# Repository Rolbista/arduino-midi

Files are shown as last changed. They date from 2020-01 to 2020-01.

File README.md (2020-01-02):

# MidiBoi™

MidiBoi™ is a controller designed for use with Korg® Monologue™. It is literally just two reprogrammable mod wheels.  
Because Monologue™ only has one pitch-stick, dynamic modulation is limited when playing by hand since it's  impossible  
to do, for example, pitch bend and add vibrato at the same time conveniently. LFO int knob is on the other side of  
the synthesizer. Why not use a standard MIDI keyboard with normal wheels then? Well, while standard Pitch Bend MIDI  
message is accepted and interpreted by the synth, Mod Wheel message is not. LFO intensity is assigned to MIDI CC 26  
so it won't react unless you reprogram the wheel to send it. I could not find a controller that would let me do this,  
space was also a consideration - since the Monologue™ already has a keyboard and doesn't exist in a module form apart  
from some risky looking mods, why take up space with another if two wheels are all that is necessary to add  
expressiveness to the interface? Potentiometers with programmable CC messages are useful in cases where hardware is  
fixed and cannot easily accept a different value like you would on a DAW by just using MIDI Learn. While it was built  
with a specific model in mind, this can be used with other synthesizers as well if you need additional mod wheel or  
two or want a comfortable wheel to steer a parameter not present on the panel.

## Setup  

The default selected board is Arduino Pro Micro or clone because of its small size and native USB capability which  
allows you to use it with your DAW without any extra fuss. The library dependencies are in the sketch.  
Open the `./switcher_one_pot.ino` sketch, update the pins as appropriate and upload it.

## Usage

MidiBoi™ is powered by USB, just plug one of those old phone chargers that you have lying around that will surely  
come in handy one day - now is their time to shine! Use a standard DIN MIDI cable to connect MidiBoi™ output to  
synth MIDI input. Default CC are 26 (LFO intensity) for wheel 1 and 24 (LFO rate) for wheel 2. When the controller  
powers up it works in default, loop mode, sending default messages. To reprogram wheel 1 push the encoder button once,  
select the desired wheel number (1), press the button again. Now select new CC message (0-119) keeping in mind your  
synths MIDI implementation. Press the button again to save the change. Now wheel one send a new CC message and you  
instrument should react accordingly.

## Features

* Segment display showing current wheel/potentiometer/MIDI CC selected
* Encoder for value input
* Support for n potentiometers with reprogrammable CCs limited only by number of ADC pins on selected Arduino board
* USB and DIN5 MIDI output on channel 1
* Extensibility: with little modification of the hardware any MIDI parameter can be controlled with any type of analog device - add a jack for an expression pedal if you like

## Roadmap  

* Support for storing and saving potentiometer configs in EEPROM
* Software MIDI passthrough so the only DIN jack on target synth is not taken up
* Possibly OLED screen for clearer information display
* Channel reprogrammability
* Higher bit resolution (10 bit, allowed by Control-Surface library)
* Example PCB design (Kicad single-sided board)

## Additional info

Libraries used:  
https://github.com/tttapa/Control-Surface  
https://github.com/mathertel/RotaryEncoder  
https://github.com/avishorp/TM1637

Monologue MIDI Implementation Chart:  
https://www.korg.com/us/support/download/manual/0/733/3519/  
https://bit.ly/2ZH0zTO (page 58)

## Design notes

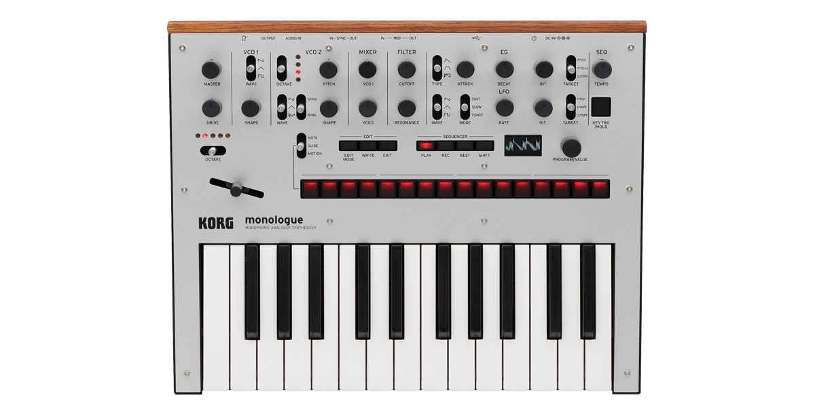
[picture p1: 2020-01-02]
hardware/Korg-monologue-top.jpg

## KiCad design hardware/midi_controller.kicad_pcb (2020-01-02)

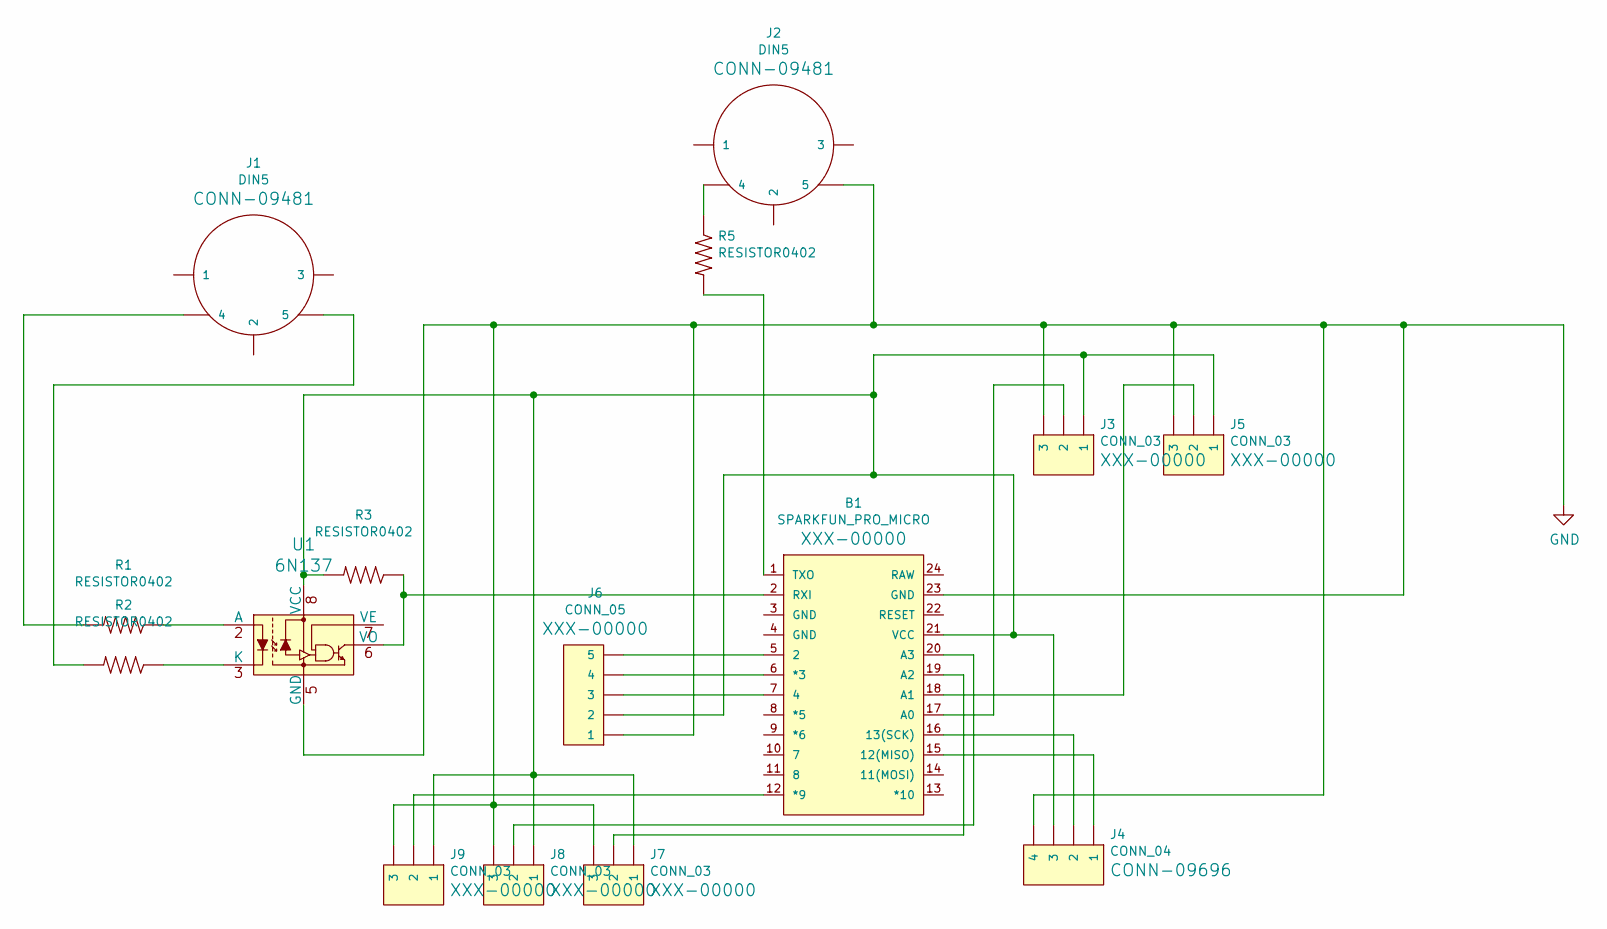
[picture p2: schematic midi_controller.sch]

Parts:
B1: SPARKFUN_PRO_MICRO
J1, J2: DIN5; DIN5-RA-PTH
J3, J5, J7, J8, J9: CONN_03; 1X03
J4: CONN_04; 1X04
J6: CONN_05; 1X05
R1, R2, R3, R5: RESISTOR0402; Resistor_SMD+THTuniversal_2512_RM10_HandSoldering_RevA_Date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
U1: 6N137; DIP-8_W7.62mm; MPN 6N137; Digi-Key_PN 160-1791-ND

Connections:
GND: B1.23 (GND), J2.5, J3.3, J4.4, J5.3, J6.1, J7.3, J8.3, J9.3, U1.5 (GND)
unnamed: B1.1 (TXO), R5.2
unnamed: B1.2 (RXI), R3.1, U1.6 (VO)
unnamed: B1.5 (2), J6.5
unnamed: B1.6 (*3), J6.4
unnamed: B1.7 (4), J6.3
unnamed: B1.12 (*9), J9.2
unnamed: B1.15 (12(MISO)), J4.1
unnamed: B1.16 (13(SCK)), J4.2
unnamed: B1.17 (A0), J3.2
unnamed: B1.18 (A1), J5.2
unnamed: B1.19 (A2), J7.2
unnamed: B1.20 (A3), J8.2
unnamed: B1.21 (VCC), J3.1, J4.3, J5.1, J6.2, J7.1, J8.1, J9.1, R3.2, U1.8 (VCC)
unnamed: J1.4, R1.2
unnamed: J1.5, R2.2
unnamed: J2.4, R5.1
unnamed: R1.1, U1.2 (A)
unnamed: R2.1, U1.3 (K)

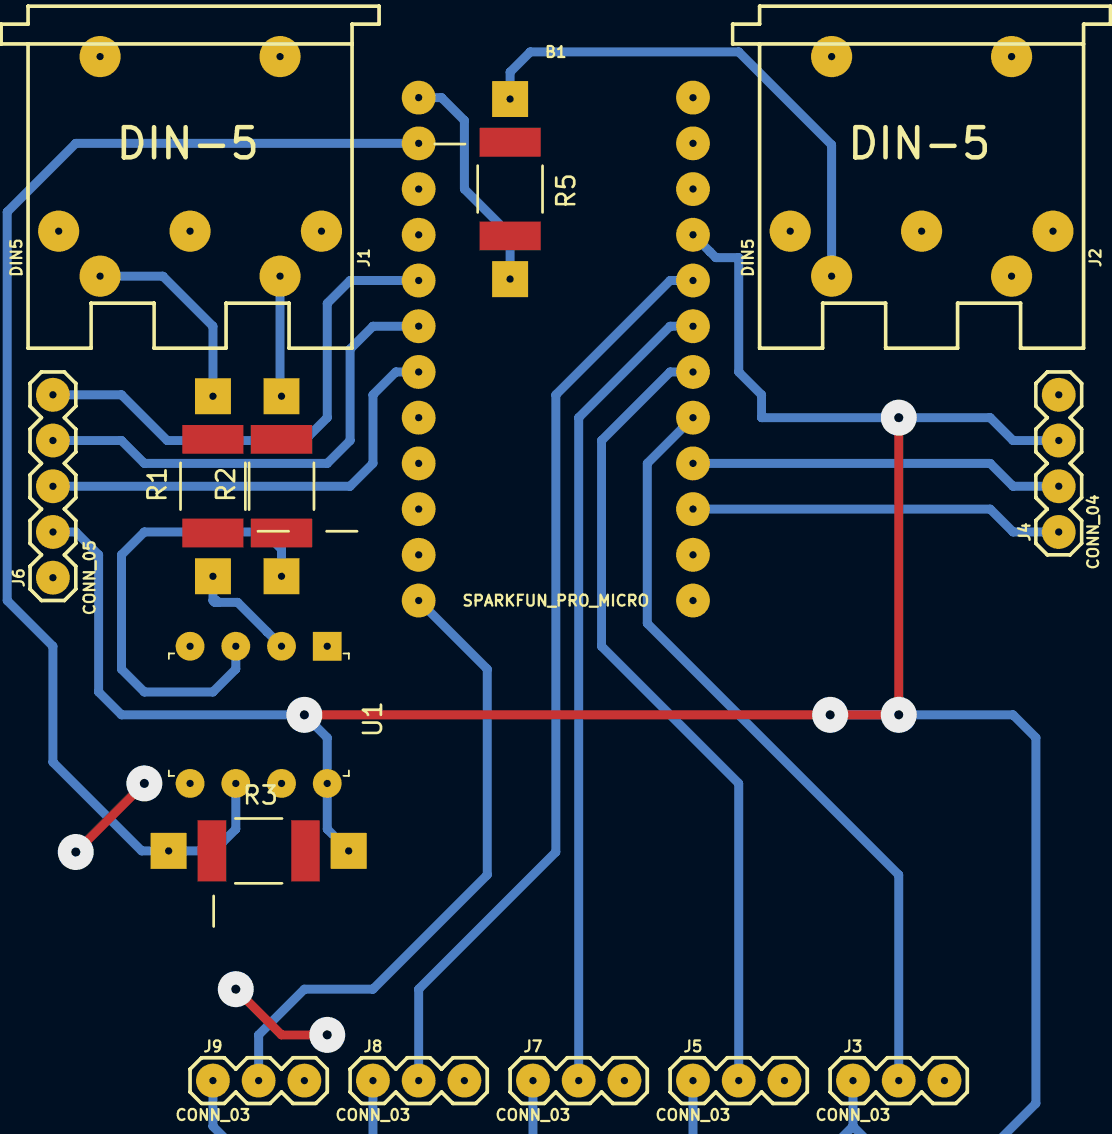
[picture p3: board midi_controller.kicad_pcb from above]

Board: 2 copper layers, 15 parts (0 on the bottom side), 19 nets.

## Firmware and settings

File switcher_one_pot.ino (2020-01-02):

#include <TM1637Display.h>
#include <RotaryEncoder.h> // Separate encoder library for now due to better performance than using "Encoder.h"
// Encoder must be included before Control Surface
#include <Encoder.h>
#include <Control_Surface.h> // Include the library

int modWheelMsg[] = {
  26,
  24
}; // Initial CC numbers TODO: move this to EEPROM.read/write

// States for mode type
enum State { MODE_LOOP, MODE_SCAN, MODE_CONFIG };
int current_state = MODE_LOOP;

int rotarySteps = 1;

bool showLastPot = false; // Switch variables to trigger single display instruction
bool showLastCC  = false;

int whichPot = 1; // Selected potentiometer

// Diagnostic display message for loop mode
const uint8_t SEG_DONE[] = {
	SEG_A | SEG_D | SEG_E | SEG_F,          // C
	SEG_B | SEG_C | SEG_E | SEG_F | SEG_G,  // H
	SEG_B | SEG_C | SEG_D | SEG_E | SEG_F,  // U
	SEG_B | SEG_C | SEG_D                   // J
};
// Create a display instance
TM1637Display display(14, 15);

// Create two MIDI interfaces
USBMIDI_Interface usbmidi;
HardwareSerialMIDI_Interface serialmidi = {Serial1, MIDI_BAUD};

// And group them together
MultiMIDI_Interface<2> midi = {{&usbmidi, &serialmidi}};

// Array of banks allows dynamic indexing
Bank<120> banks[] = {
  {1},
  {1}
};

// Two encoder objects on the same pins for storing recet position
RotaryEncoder encoderSelectMode(2, 3);  // Encoder for potentiometer selection
RotaryEncoder encoderConfigMode(2, 3);  // Encoder for CC Message selection

Button enc_button = {4};

// Array of potentiometers
Bankable::CCPotentiometer potentiometers[] = {
  {{banks[0], BankType::CHANGE_ADDRESS}, A0, {0x00, CHANNEL_1}}, // TODO: fix the PCB design only pins A1 and A9 functional on the pcb, some headers wrongly connected to PWM pins instead of Analog
  {{banks[1], BankType::CHANGE_ADDRESS}, A9, {0x00, CHANNEL_1}}, // investigate the board with preferably another Arduino
};

void setup() {
  // Display setup
  display.setBrightness(0x0b);

  // Encoder setup
  encoderSelectMode.setPosition(whichPot / rotarySteps );
  encoderConfigMode.setPosition(modWheelMsg[0] / rotarySteps );

  // Initial MIDI potentiometer setting
  banks[0].select(modWheelMsg[0]);
  banks[1].select(modWheelMsg[1]);

  //button setup
  enc_button.begin();
}
// Function to read encoder in a range and display the current value
int encoderConfig(RotaryEncoder* encoder, TM1637Display* display, int rotaryMin, int rotaryMax, int startPos, int rotarySteps=1) {

  encoder->tick();
  int newPos = encoder->getPosition() * rotarySteps;

  if ( newPos < rotaryMin ) {                         // Limit encoder return values
    newPos = rotaryMin;
    encoder->setPosition(rotaryMin / rotarySteps );
  } else if ( newPos > rotaryMax ) {
    newPos = rotaryMax;
    encoder->setPosition(rotaryMax / rotarySteps );
  }
  
  if ( startPos != newPos ) {
    display->showNumberDec(newPos, false, 4, 0);
    return newPos;
  } else if ( rotaryMin == rotaryMax ) {
    display->showNumberDec(newPos, false, 4, 0);
    return newPos;                                    // Special case for only one potentiometer
  } else {
    return startPos;
  }
}

void loop() {

  if ( enc_button.update() == Button::Falling ) {
    switch (current_state) {
      case MODE_LOOP:
        current_state = MODE_SCAN;
        break;
      case MODE_SCAN:
        current_state = MODE_CONFIG;
        break;
      case MODE_CONFIG:
        current_state = MODE_LOOP;
        break;
    }
  }
  
  switch (current_state) {
    case MODE_LOOP:

      display.setSegments(SEG_DONE);
      Control_Surface.loop();
      showLastPot = true;                             // Update the switch variable to display last selected potentiometer in MODE_SCAN

      break;    
    case MODE_SCAN:

      if ( showLastPot ) {                            // Display last edited potentiometer number ONCE
        display.showNumberDec(whichPot, false, 4, 0); 
        showLastPot = false;                          // Update the switch variable to not display until next mode change
      }

      whichPot = encoderConfig(&encoderSelectMode, &display, 1, 2, whichPot);
      encoderConfigMode.setPosition( modWheelMsg[whichPot - 1] * rotarySteps ); // Set config encoder to selected potentiometer's recent value so it starts from there in MODE_CONFIG

      showLastCC = true;                              // Update the switch variable to display last selected CC message in MODE_CONFIG

      break;
    case MODE_CONFIG:

      if ( showLastCC == true ) {                     // Display current CC message on currently edited potentiometer ONCE
        display.showNumberDec(modWheelMsg[whichPot - 1], false, 4, 0);
        showLastCC = false;
      }

      modWheelMsg[whichPot - 1] = encoderConfig(&encoderConfigMode, &display, 0, 119, modWheelMsg[whichPot - 1]);

      banks[whichPot - 1].select(modWheelMsg[whichPot - 1]); // -1 to account for 0-based indexing
      
      break;    
  }
}

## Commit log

2020-01-02 move encoder value display to encoderConfig() function for performance, use Button class for encoder button, refactor switch cases for readability
    add variable range to encoder
    encoder stays at saved value but is too slow to be usable
    works a bit better but still too slow, pot select doesn't work or is too slow to notice
    add encoder pointer parameter to function
    change CC message number variable to array to index with potentiometer number
    set config mode encoder start position to recent for n potentiometers
    display inital encoder value once for each MODE duration, display functional and refresh rate is fast
    [switcher_one_pot.ino]
2020-01-02 add circuit schematic, pcb design files and front panel layout
    [midi_controller.kicad_pcb, midi_controller.sch, midi_controller_board_2.kicad_pcb]
2020-01-02 fix analog pins and remove redundant resistor
    [midi_controller.kicad_pcb, midi_controller.sch, midi_controller_board_2.kicad_pcb]
